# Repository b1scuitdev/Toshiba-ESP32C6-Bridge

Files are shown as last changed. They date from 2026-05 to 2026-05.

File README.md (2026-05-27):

# 💫 Toshiba x ESP32-C6 UART Bridge
### 🌬️ ESPHome UART-to-WiFi Interface Board for Toshiba Air Conditioners

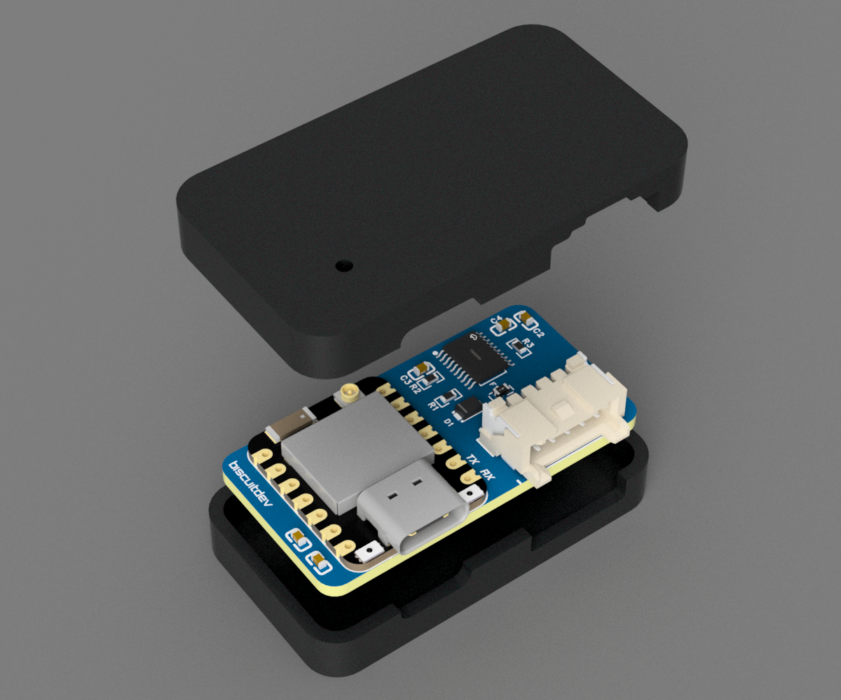
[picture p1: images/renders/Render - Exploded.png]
Toshiba x ESP32-C6 UART Bridge


Toshiba x ESP32-C6 UART Bridge is a compact interface board designed for compatible Toshiba air conditioners.  
It connects to the internal **CN22 UART connector** and allows ESPHome / Home Assistant to read the real AC state and send control commands over UART.

The board is built around the **Seeed Studio XIAO ESP32-C6** and is intended to provide a clean wired alternative to IR-only control.

## 🔗 Project Links

- 🧩 OSHWLab / EasyEDA Project: [Open Online](https://oshwlab.com/xqvc/project_wmbdnden)
- 🗂️ Gerber Files: [Download Gerber](hardware/GERBER%20-%20Toshiba%20x%20ESP32C6%20UART%20Bridge%20v1.0%20-%20Rev%20A.zip)
- 📄 Schematic PDF: [View Schematic](hardware/SCHEMATIC%20-%20Toshiba%20x%20ESP32C6%20UART%20Bridge%20v1.0%20-%20Rev%20A.pdf)
- 📦 BOM: [Download BOM](hardware/BOM%20-%20ESP32C6%20UART%20Bridge%20v1.0%20-%20Rev%20A.xlsx)
- 🧾 Pick and Place: [Download PnP](hardware/PickAndPlace%20-%20Toshiba%20x%20ESP32C6%20UART%20Bridge%20v1.0%20-%20Rev%20A.xlsx)
- 🖨️ 3D Printable Enclosure: [Download 3MF](hardware/Toshiba%20x%20ESP32C6%20Bridge%20Enclosure.3mf)

## ✨ Features

- **Seeed Studio XIAO ESP32-C6**
- **ESPHome** firmware configuration
- Toshiba AC control over internal **CN22 UART**
- Real AC state feedback, not just IR commands
- Home Assistant API support
- OTA update support after first USB flash
- Wi-Fi fallback access point
- AC Wi-Fi LED control
- Off timer support
- Compact custom PCB design

## 🔧 Hardware Overview

The board connects the **XIAO ESP32-C6** to the Toshiba indoor unit through the internal **CN22 UART** connector.

UART settings used by the firmware:

    Baud rate: 9600
    Parity: EVEN
    ESP32 TX: GPIO1
    ESP32 RX: GPIO0

Connection direction:

    ESP32 TX -> Toshiba RX
    ESP32 RX <- Toshiba TX

Always check your own AC unit's CN22 pinout before connecting the board.

## 🧠 Firmware

The firmware is based on **ESPHome** and uses the external Toshiba Suzumi ESPHome component:

https://github.com/pedobry/esphome_toshiba_suzumi

Firmware files are located in:

    firmware/esphome/

Main configuration:

    firmware/esphome/toshiba-uart.yaml

Before compiling, edit the placeholder secrets file:

    firmware/esphome/secrets.yaml

Do not commit real Wi-Fi credentials if you fork or modify this repository; untrack `firmware/esphome/secrets.yaml` and add it to `.gitignore` before entering real values.

## 🧪 Compatibility

This board has only been tested with a **Toshiba Seiya** air conditioner.

It will likely work with other Toshiba air conditioners that use the same internal **CN22 UART** interface, but this has not been verified.  
Always check your own unit's connector, pinout, and documentation before connecting the board.

## 🖼️ Images

### PCB

PCB Top

PCB Bottom

### Enclosure

3D Enclosure

3D Enclosure Side View

### Renders

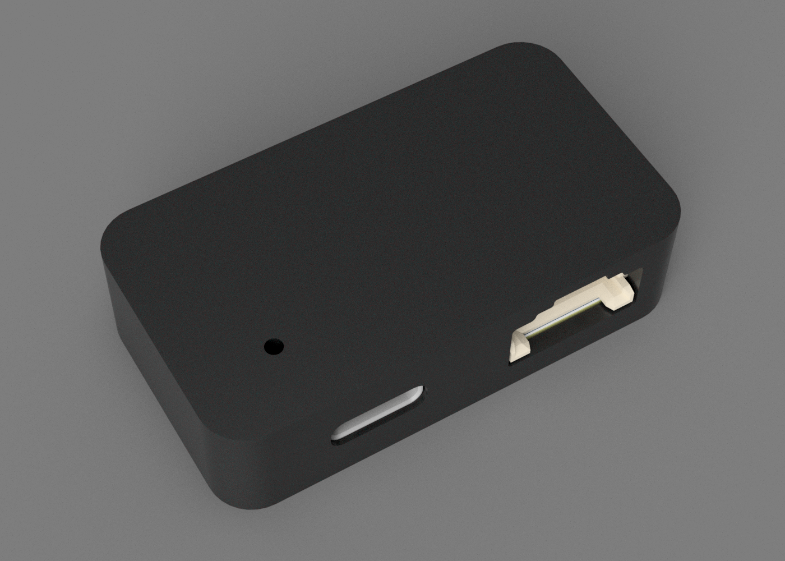
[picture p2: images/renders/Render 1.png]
Render 1


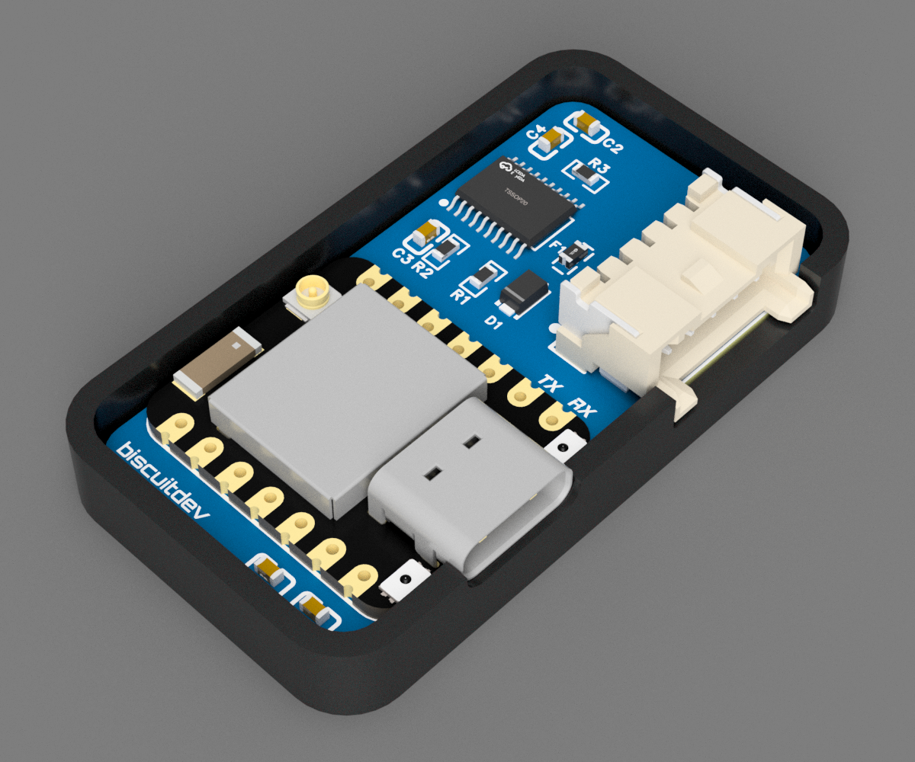
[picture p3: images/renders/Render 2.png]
Render 2


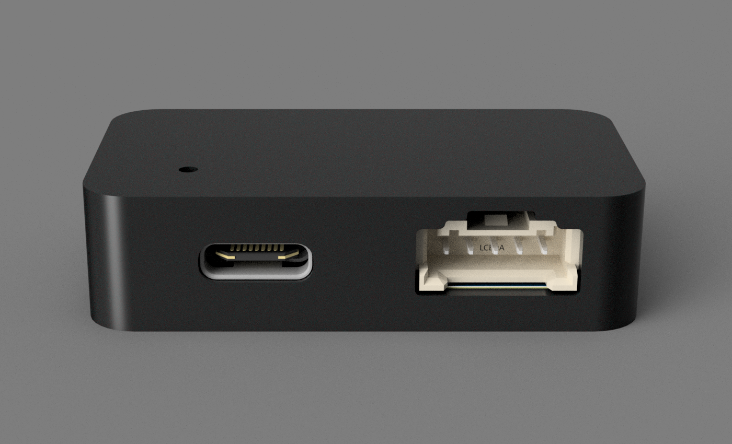
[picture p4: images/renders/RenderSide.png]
Render Side


Exploded Render

### Connected to AC

Connected to AC

## ⚠️ Safety

This board is only intended for the **low-voltage UART interface side** of the air conditioner.

- Disconnect AC power before opening the air conditioner.
- Do not work on the unit while it is connected to mains power.
- Do not connect this board to mains voltage.
- Check the PCB for solder bridges, missing parts, wrong parts, or damaged components before powering it.
- Verify the fuse with a multimeter continuity test.
- Check the Schottky diode direction before powering the board.
- Confirm connector orientation and cable order.

**NEVER connect USB power while the board is connected to the air conditioner.**  
The Schottky diode helps prevent current from feeding back into the air conditioner interface, but it does not protect the USB connector side. With both connections present, the air conditioner side may backfeed into the USB port, which can damage your computer, the board, or the AC control board, and may also blow the onboard fuse.

Use this hardware at your own risk.

## 📜 License

This repository uses separate licenses for hardware and firmware.

### Hardware

Hardware design files are licensed under the **CERN Open Hardware Licence Version 2 - Strongly Reciprocal (CERN-OHL-S-2.0)**.

See [`LICENSE_HARDWARE`](LICENSE_HARDWARE) for details.

### Firmware

Firmware and ESPHome configuration files are licensed under **GPL-3.0-only**.

See [`LICENSE_SOFTWARE`](LICENSE_SOFTWARE) for details.

The external Toshiba Suzumi ESPHome component is licensed by its original author under the **GNU General Public License v3.0**.

## ⚠️ Disclaimer

This project is provided for educational and personal use.

The author takes no responsibility for any damage, misuse, electrical faults, AC unit damage, computer damage, or installation mistakes.  
By using this hardware and firmware, you agree that all responsibility is yours.

This project is provided **"as-is"** without any warranty.

## 👨‍💻 Author

Designed by **Yiğit Alp Eltutan (biscuitdev)**

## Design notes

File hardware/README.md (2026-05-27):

# Hardware

This folder contains the hardware files for the **Toshiba x ESP32-C6 UART Bridge**.

The board is designed around the **Seeed Studio XIAO ESP32-C6** and connects to the internal **CN22 UART connector** of compatible Toshiba air conditioners.

It is used with ESPHome to read the real AC state and send control commands over UART.

## Files

- `SCHEMATIC - Toshiba x ESP32C6 UART Bridge v1.0 - Rev A.pdf`  
  Schematic export.

- `GERBER - Toshiba x ESP32C6 UART Bridge v1.0 - Rev A.zip`  
  Gerber files for PCB manufacturing.

- `BOM - ESP32C6 UART Bridge v1.0 - Rev A.xlsx`  
  Bill of materials.

- `PickAndPlace - Toshiba x ESP32C6 UART Bridge v1.0 - Rev A.xlsx`  
  Pick and place / assembly file.

## Compatibility

This board has only been tested with a **Toshiba Seiya** air conditioner.

It will likely work with other Toshiba air conditioners that use the same internal **CN22 UART** interface, but this has not been verified. Always check your own unit's connector, pinout, and service documentation before connecting the board.

## UART

UART settings used by the ESPHome firmware:

    Baud rate: 9600
    Parity: EVEN
    ESP32 TX: GPIO1
    ESP32 RX: GPIO0

Connection direction:

    ESP32 TX -> AC RX
    ESP32 RX <- AC TX

Check your own AC unit's **CN22 pinout** before connecting the board.

## Before Powering On

Before connecting or powering the board:

- Turn off the circuit breaker or completely disconnect AC power to the air conditioner.
- Do not work on the unit while it is connected to mains power.
- Check the PCB carefully for solder bridges, missing parts, wrong parts, or damaged components.
- Verify the orientation of polarized components.
- Check the Schottky diode direction before powering the board.
- Confirm connector orientation and cable order.
- Make sure the board is only connected to the low-voltage UART side of the air conditioner.

## Safety

This board is only intended for the low-voltage UART interface side of the air conditioner.

Do **not** connect it to mains voltage.

Air conditioners contain dangerous voltages inside. Disconnect AC power before opening the unit or connecting this board.

Use this hardware at your own risk.

## License

Hardware files are licensed under **CERN-OHL-S-2.0**.

See `../LICENSE_HARDWARE` for details.

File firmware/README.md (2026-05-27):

# Firmware

This folder contains the ESPHome firmware configuration for the **Toshiba x ESP32-C6 UART Bridge**.

The firmware runs on a **Seeed Studio XIAO ESP32-C6** and uses the external Toshiba Suzumi ESPHome component to communicate with compatible Toshiba air conditioners over the internal CN22 UART interface.

## Files

- `esphome/toshiba-uart.yaml`  
  Main ESPHome configuration.

- `esphome/secrets.yaml`  
  Example secrets file with placeholder Wi-Fi values.

## ESPHome Component

This firmware uses the external Toshiba Suzumi ESPHome component:

https://github.com/pedobry/esphome_toshiba_suzumi

That component is licensed by its original author under the **GNU General Public License v3.0**.

## Board

Target board:

    Seeed Studio XIAO ESP32-C6

ESPHome board configuration:

    board: seeed_xiao_esp32c6
    variant: esp32c6
    framework: esp-idf

## UART

UART settings used to communicate with the Toshiba AC unit:

    Baud rate: 9600
    Parity: EVEN
    ESP32 TX: GPIO1
    ESP32 RX: GPIO0

Connection direction:

    ESP32 TX -> Toshiba RX
    ESP32 RX <- Toshiba TX

Always check your own AC unit's CN22 pinout before connecting the board.

## Features

- Toshiba AC control through ESPHome
- Real AC state feedback over UART
- Home Assistant API support
- OTA updates
- Wi-Fi fallback access point
- Wi-Fi signal and uptime sensors
- AC Wi-Fi LED control
- Off timer support
- XIAO ESP32-C6 onboard antenna switch setup

## Secrets

Before compiling, edit:

    firmware/esphome/secrets.yaml

Example:

    wifi_ssid: "YOUR_WIFI_NAME"
    wifi_password: "YOUR_WIFI_PASSWORD"
    fallback_ap_password: "YOUR_FALLBACK_AP_PASSWORD"

Do not commit real Wi-Fi credentials if you fork or modify this repository; untrack `firmware/esphome/secrets.yaml` and add it to `.gitignore` before entering real values.

## Build

From the `firmware/esphome` folder:

    esphome config toshiba-uart.yaml

To compile:

    esphome compile toshiba-uart.yaml

To upload:

    esphome run toshiba-uart.yaml

The first upload may require USB. After that, OTA updates can be used if the device is connected to Wi-Fi.

## License

Firmware files in this repository are licensed under **GPL-3.0-only**.

See `../LICENSE_SOFTWARE` for details.

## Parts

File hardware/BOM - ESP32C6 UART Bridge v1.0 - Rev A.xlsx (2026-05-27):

No. | Quantity | Comment | Designator | Value | Manufacturer Part | Manufacturer
1 | 3 | 22uF | C1,C2,C5 | 22uF | GRM188R61A226ME15D | muRata(村田)
2 | 2 | 100nF | C3,C4 | 100nF | CL10B104KB8NNNC | SAMSUNG(三星)
3 | 1 | PMEG2010ER,115 | D1 |  | PMEG2010ER,115 | Nexperia(安世)
4 | 1 | ERB-RE0R75V | F1 |  | ERB-RE0R75V | PANASONIC(松下)
5 | 1 | 10kΩ | R1 | 10kΩ | RC0603FR-0710KL | YAGEO(国巨)
6 | 2 | 47Ω | R2,R3 | 47Ω | RC0603FR-0747RL | YAGEO(国巨)
7 | 1 | XIAO-ESP32-C6 | U1 |  | XIAO-ESP32-C6 | Seeed Studio
8 | 1 | TXS0108EPWR | U2 |  | TXS0108EPWR | Texas Insturments
9 | 1 | SM05B-PASS-TBT(LF)(SN) | X1 |  | SM05B-PASS-TBT(LF)(SN) | JST

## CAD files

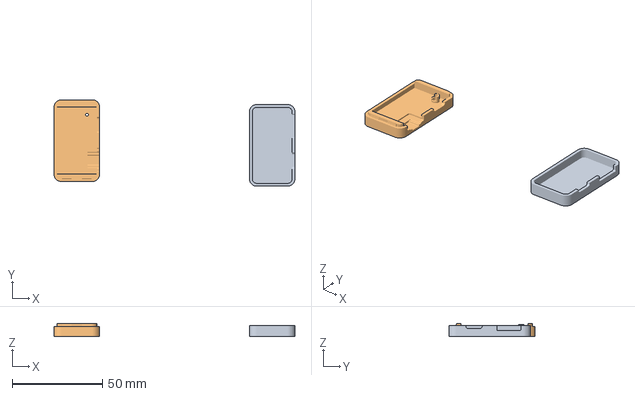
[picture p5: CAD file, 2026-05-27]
hardware/Toshiba x ESP32C6 Bridge Enclosure.3mf
133.5 x 47.9 x 7.00 mm
Bottom
Top

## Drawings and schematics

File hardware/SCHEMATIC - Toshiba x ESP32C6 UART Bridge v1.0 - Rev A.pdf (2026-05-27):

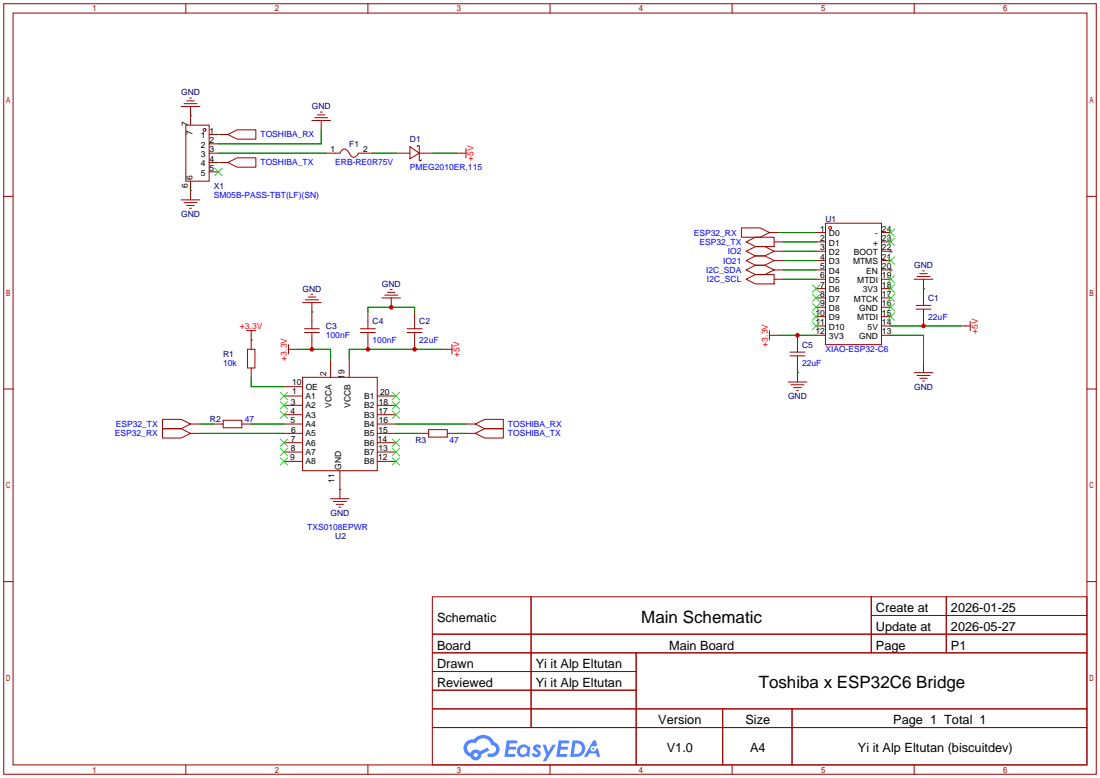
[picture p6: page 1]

Schematic | Main Schematic | Create at | 2026-01-25

Update at | 2026-05-27

Board | Main Board | Page | P1
Drawn | Yi it Alp Eltutan | Toshiba x ESP32C6 Bridge
Reviewed | Yi it Alp Eltutan

Version | Size | Page 1 Total 1
V1.0 | A4 | Yi it Alp Eltutan (biscuitdev)
